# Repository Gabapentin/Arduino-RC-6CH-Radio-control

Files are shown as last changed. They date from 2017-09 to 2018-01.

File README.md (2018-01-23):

# Arduino-RC-6CH-Radio-control

----------------------------------------------------------------------------------------------------------

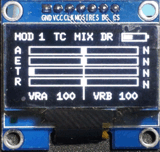
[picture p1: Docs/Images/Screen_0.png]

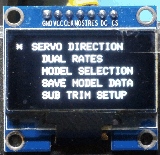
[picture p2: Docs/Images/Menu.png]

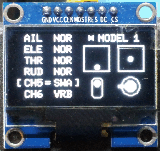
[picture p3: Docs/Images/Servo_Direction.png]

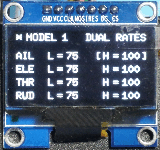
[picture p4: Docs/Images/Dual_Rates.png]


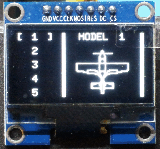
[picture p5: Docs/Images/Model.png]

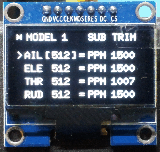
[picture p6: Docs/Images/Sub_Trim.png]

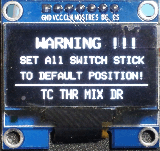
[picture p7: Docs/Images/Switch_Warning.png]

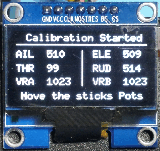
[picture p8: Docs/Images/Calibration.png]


| FS-CT6B | | HK-T6A |
| --- | :---: | --- |
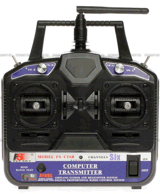
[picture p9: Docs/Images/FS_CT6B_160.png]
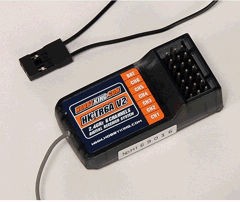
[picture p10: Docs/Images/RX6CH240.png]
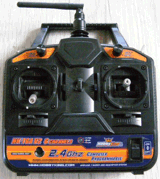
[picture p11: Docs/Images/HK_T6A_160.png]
|  |  |  | 

Arduino project to upgrade cheap Hobbyking HK-T6A or Flysky FS-CT6B transmitters or any other old RC TX    

This code is based on ardutx v1.3 sketch (2014) from Patricio Reinoso www.patolin.com    

**You can see discussion on RCGroups Forum site**    
https://www.rcgroups.com/forums/showthread.php?1817699-Hobbyking-6ch-tx-arduino-computer-update

**If you want discuss this project I have already open thread on RCGroups**    
https://www.rcgroups.com/forums/showthread.php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 

----------------------------------------------------------------------------------------------------------

The code has been modified to work with SH1106 SPI 1.3" or SSD1306 SPI 0.96" OLED LCD through U8g2 library

Have been used all possible pins of ATmega328P (Arduino Nano, Pro Mini)

Every text strings has been stored in flash memory to mantain a lot of free RAM memory

----------------------------------------------------------------------------------------------------------

Added features to original Patolin code:

- 3 digital buttons input for menu (Enter/Select) (Down/Next) (Up/Previous) [previously analogs]

- Switches checking status with sound alert at power ON and display which is not in default position 

- Throttle warning with display status of switches and sound alert

- Hidden data default restoring by pressing and hold Down/Next button on power on

- Hidden calibration procedure by pressing and hold Menu/Select button on power on

- Low battery control in real time whith buzzer sound(buzzer with stand alone sound generator)

- N°2 supplementary switch, they can be configured instead of VRA or VRB pots (SWA, SWB)(Servo Direction Menu)

- Basic two channel mixer with switch activation V-Mix (Ch1/ch2)

- Basic four channels Sub Trim setting (ch1, ch2, ch3, ch4)

*************************************************************************************************************

Recommended Arduino **[Arduino IDE 1.8.2 or above](https://www.arduino.cc/en/main/software)**    
(Seems to be optimized and stable compiler. Less Flash and RAM used)

Arduino AVR Boards 1.6.18

#include <U8g2lib.h>               Using U8G2 library **[UG2 Github link](https://github.com/olikraus/U8g2_Arduino)**

#include <SPI.h>                   Arduino standard library

#include <EEPROM.h>                Arduino standard library    

### **[See Wiki pages](https://github.com/Gabapentin/Arduino-RC-6CH-Radio-control/wiki)**

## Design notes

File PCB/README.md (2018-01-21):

This directory will contain Eagle files for PCB production
you can make your own PCB    
For one layer PCB seems to be comfortable to use Arduino NANO version
* #### **WITH TRANSMITTER POWERED DIRECTLY FROM BATTERY** 
#### **DO NOT USE this PCB for Hobbyking HK-T6A or Flysky FS-CT6B original Transmitter module**
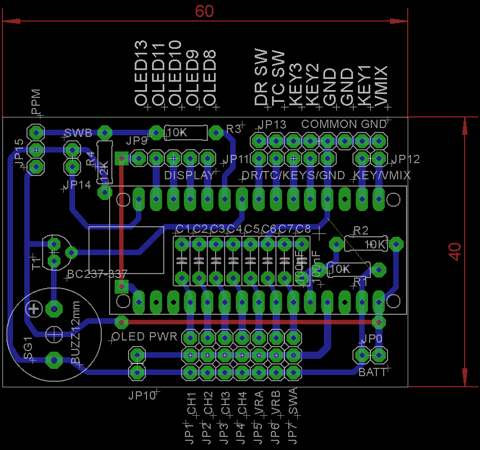
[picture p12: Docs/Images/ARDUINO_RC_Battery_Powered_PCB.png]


***

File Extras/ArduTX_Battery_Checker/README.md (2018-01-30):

## **Sketch file for calibrate battery and testing low battery alarm with OLED display**

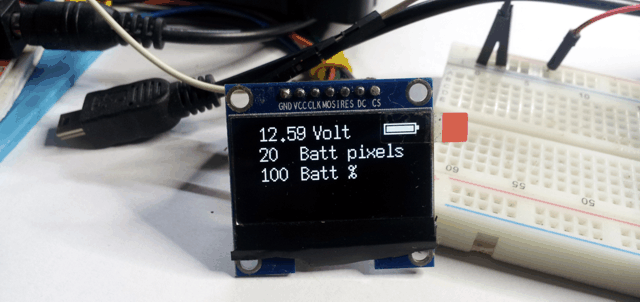
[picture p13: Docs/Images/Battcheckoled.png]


This sketch want provide help for testing and calibrate battery value from Arduino pin    
with low battery alarm functionality through OLED display (without connecting buzzer)    

**NOTES and safety WARNING:**

   - Use linear voltage variable power supply to simulate voltage battery, when it possible.
   
   - If you want a correct visualization of values after uploading sketch in Arduino    
     is necessary remove USB programming cable from PC because it makes readings unstable.  
   - **[Must be used R1-10K/R2-10K voltage divider for 2S(8.4V) lion/LiPo battery](https://github.com/Gabapentin/Arduino-RC-6CH-Radio-control/wiki/4.6-(Battery-Monitor-Wiring))**    
   - **[Must be used R1-20K/R2-10K voltage divider for 3S(12.6V) lion/LiPo battery](https://github.com/Gabapentin/Arduino-RC-6CH-Radio-control/wiki/4.6-(Battery-Monitor-Wiring))**
   - **For 2S voltage divider do not over 10V, For 3S voltage divider do not over 15V.
     Otherwise Arduino pin will be fried.**
     
   - **WARNING: If you want reset ALARM OLED display indication!    
     is necessary to put battery voltage to the maximum and restart Arduino with reset button**  

  ## For testing you can modify these parameters:
   
   **Number of reading to calculate average    
   lower value means fast reaction, high value slow reaction (8 value is maximum)**
   
```javascript
   const int numReadings = 8;
   ```
   ```javascript
   #define minBat 70     // Minimum battery voltage for alarm (70 = 7.0V)for 2S LiOn/LiPo battery
   #define maxBat 82     // Maximum battery voltage (10V) (82 = 8.2V)for 2S LiOn/LiPo battery
  
   ++++++++++++++++++++++++++++++++++++++++++++++++++++++++++++++++++++++++++++++++++++++++++++++
   #define minBat 100    // Minimum battery voltage for alarm (100 = 10V)for 3S LiOn/LiPo battery
   #define maxBat 125    // Maximum battery voltage (125 = 12.5V)for 3S LiOn/LiPo battery
   ++++++++++++++++++++++++++++++++++++++++++++++++++++++++++++++++++++++++++++++++++++++++++++++    
   ```

   **If you need more precision, measure voltage divider resistors value with digital multimeter    
   put them in to R1/R2 variables and trim these values**
   ```javascript
   float R1 = 10430;
   float R2 = 10055;
   ```
## **After ending test you need to put result values in config.h file**    

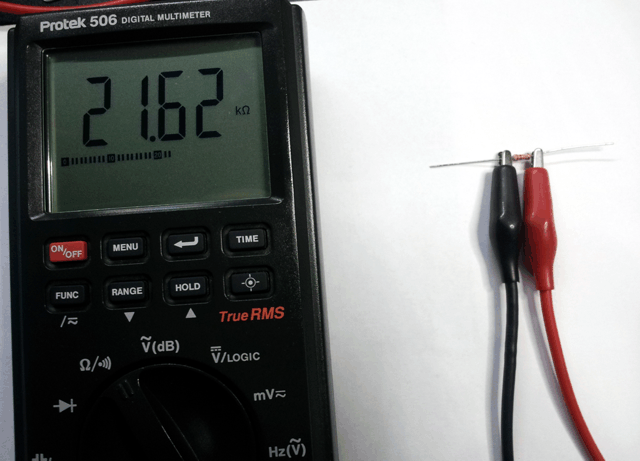
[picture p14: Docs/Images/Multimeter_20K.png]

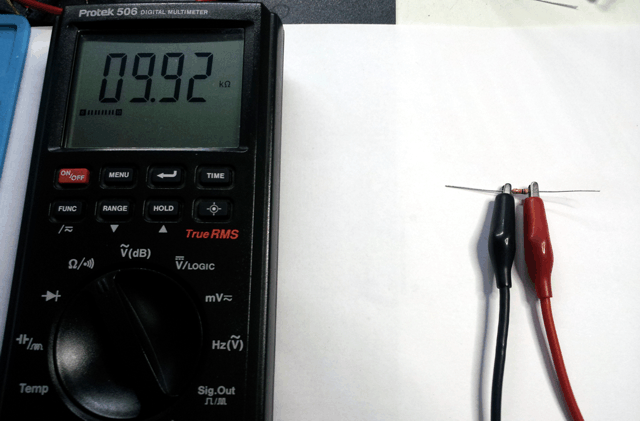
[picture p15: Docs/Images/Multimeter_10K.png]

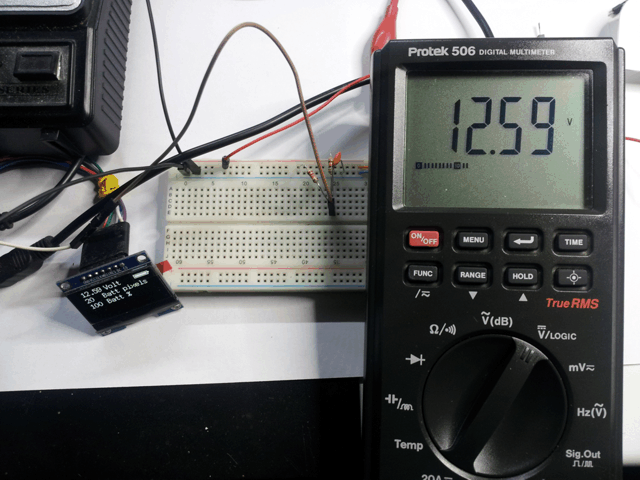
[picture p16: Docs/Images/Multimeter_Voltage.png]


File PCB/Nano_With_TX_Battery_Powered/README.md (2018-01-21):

### **Please remember at this time It's only prototype. Will be modified!** ###    
#### This directory contains all files for Arduino Nano one layer PCB shield (60x40mm dimension)   
#### This shield will provide directly battery power to TX module like **[Multiprotocol](https://github.com/pascallanger/DIY-Multiprotocol-TX-Module)** or FRSKY/FLYSKY external module     

### **DO NOT USE this PCB for Hobbyking HK-T6A or Flysky FS-CT6B original Transmitter module**
#### NOTES:
* #### Arduino Nano must be mounted on a female header socket to permit capacitors mounting under Nano module    
* #### Maximum battery voltage is 10V (2S Lion/LiPo 8.4V is enough for long time operation)
* #### For 3S 12.6V battery voltage is necessary to modify R1 to 20K and some parameters on sketch
* #### PPM voltage is reduced from voltage divider to 2.7Vpp    



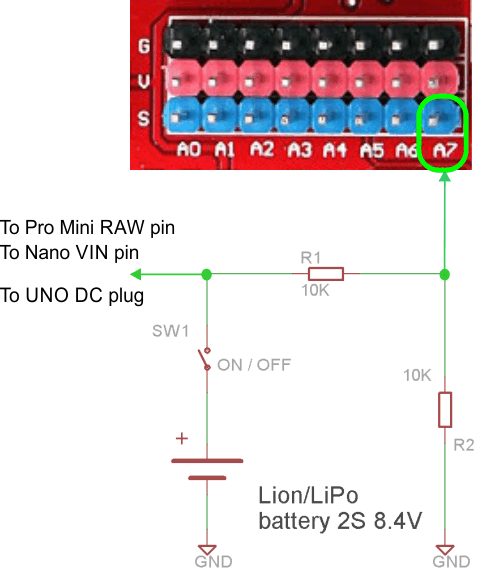
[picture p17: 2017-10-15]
Docs/Images/Battery_480.png

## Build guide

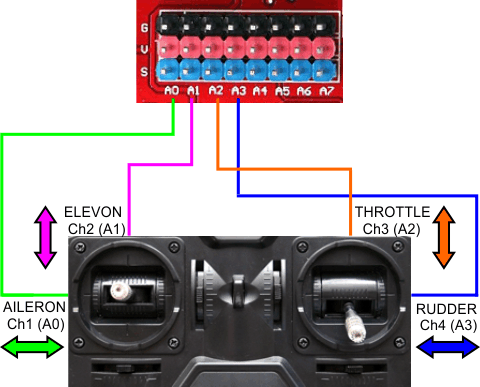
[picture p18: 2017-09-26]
Docs/Images/Gimbals_wiring_mode3_480.png

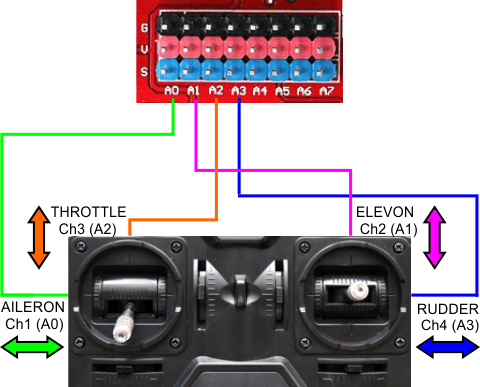
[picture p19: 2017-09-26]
Docs/Images/Gimbals_wiring_mode4_480.png

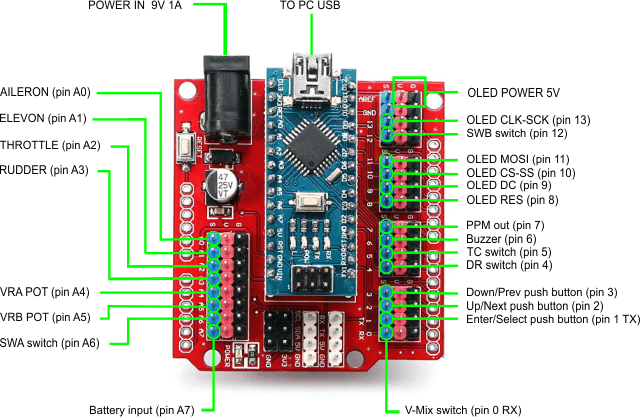
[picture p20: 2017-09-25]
Docs/Images/Arduino_Wiring.png

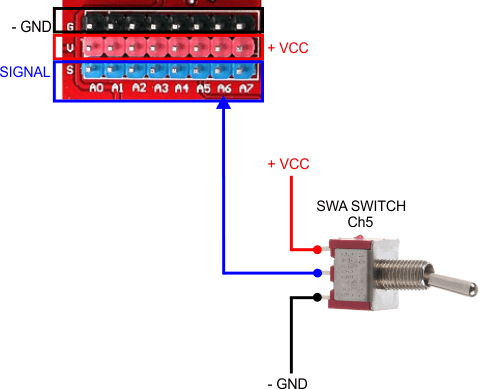
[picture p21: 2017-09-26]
Docs/Images/Switch_wiring_1_480.png

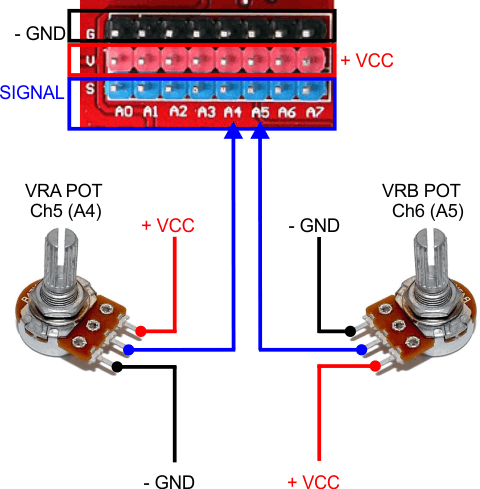
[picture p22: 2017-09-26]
Docs/Images/Pots_wiring_480.png

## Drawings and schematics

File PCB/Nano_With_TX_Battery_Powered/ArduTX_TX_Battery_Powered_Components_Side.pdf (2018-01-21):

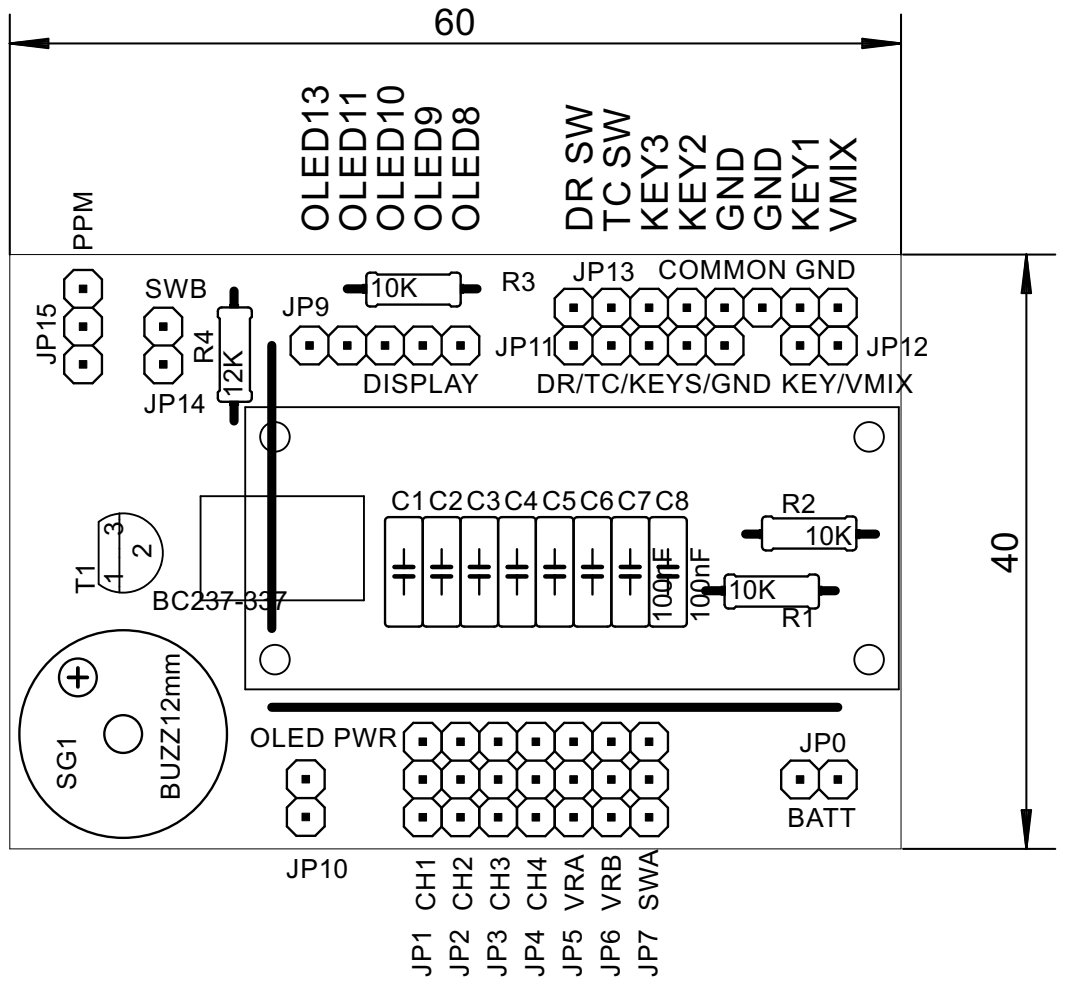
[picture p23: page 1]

DR/TC/KEYS/GND KEY/VMIX

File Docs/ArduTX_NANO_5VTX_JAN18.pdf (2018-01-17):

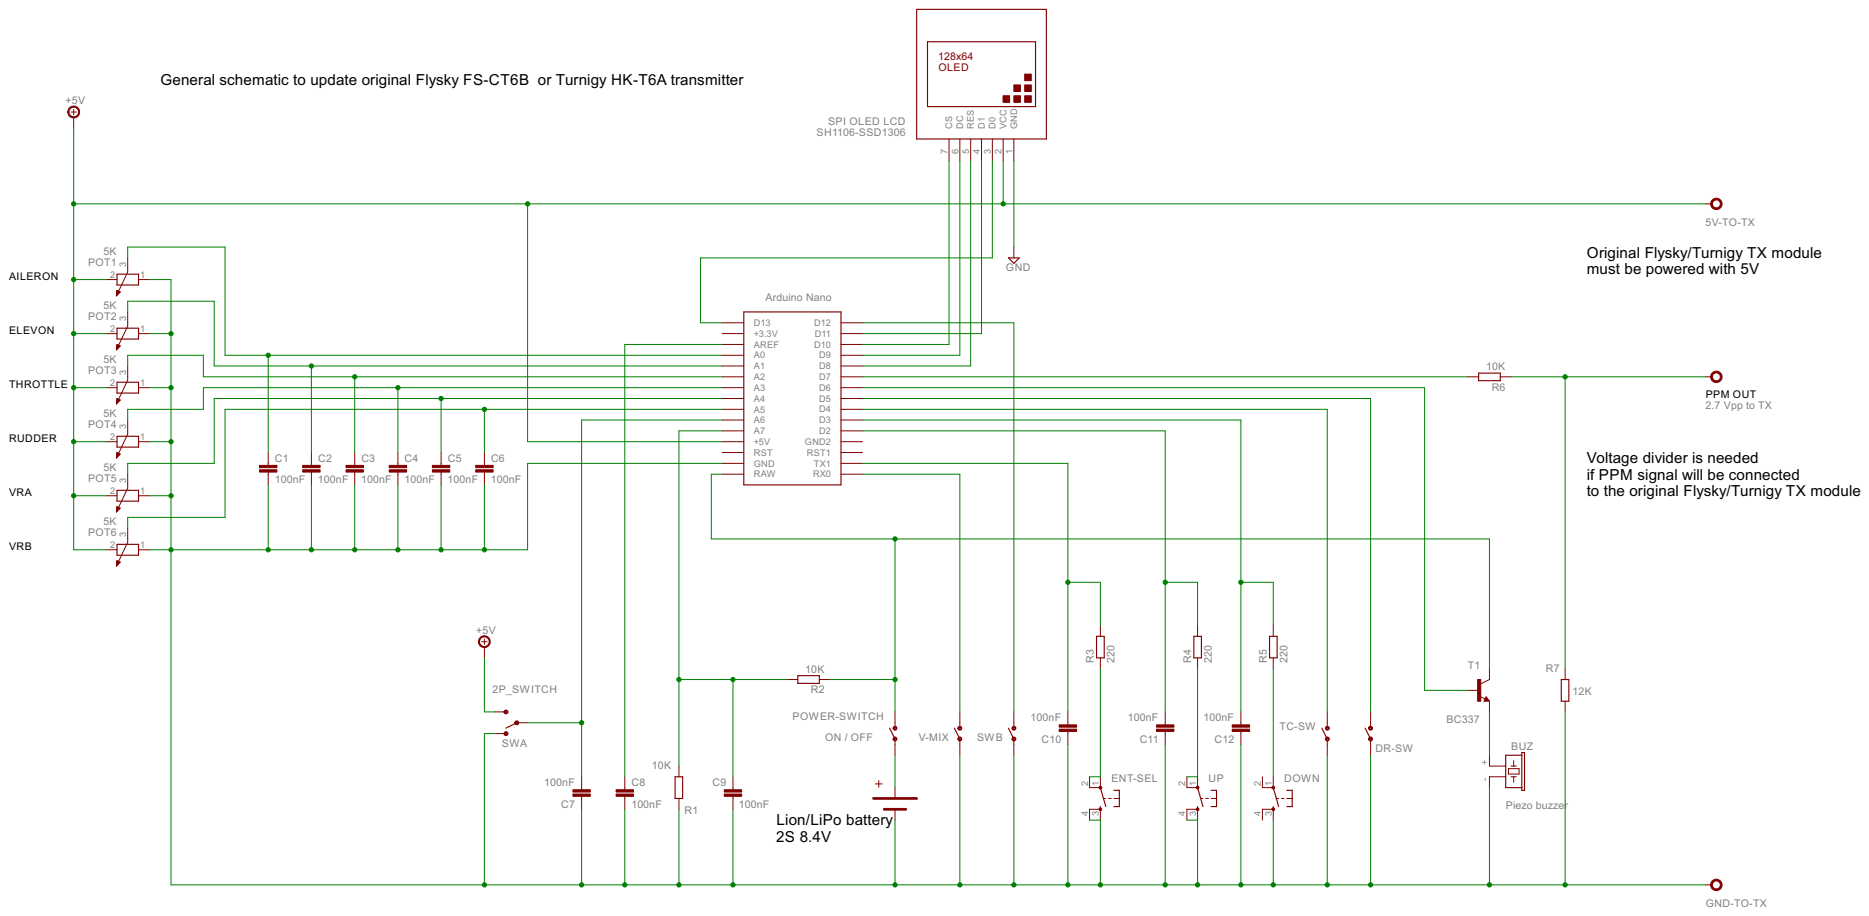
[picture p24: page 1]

General schematic to update original Flysky FS-CT6B or Turnigy HK-T6A transmitter

Original Flysky/Turnigy TX module must be powered with 5V

Voltage divider is needed
if PPM signal will be connected
to the original Flysky/Turnigy TX module

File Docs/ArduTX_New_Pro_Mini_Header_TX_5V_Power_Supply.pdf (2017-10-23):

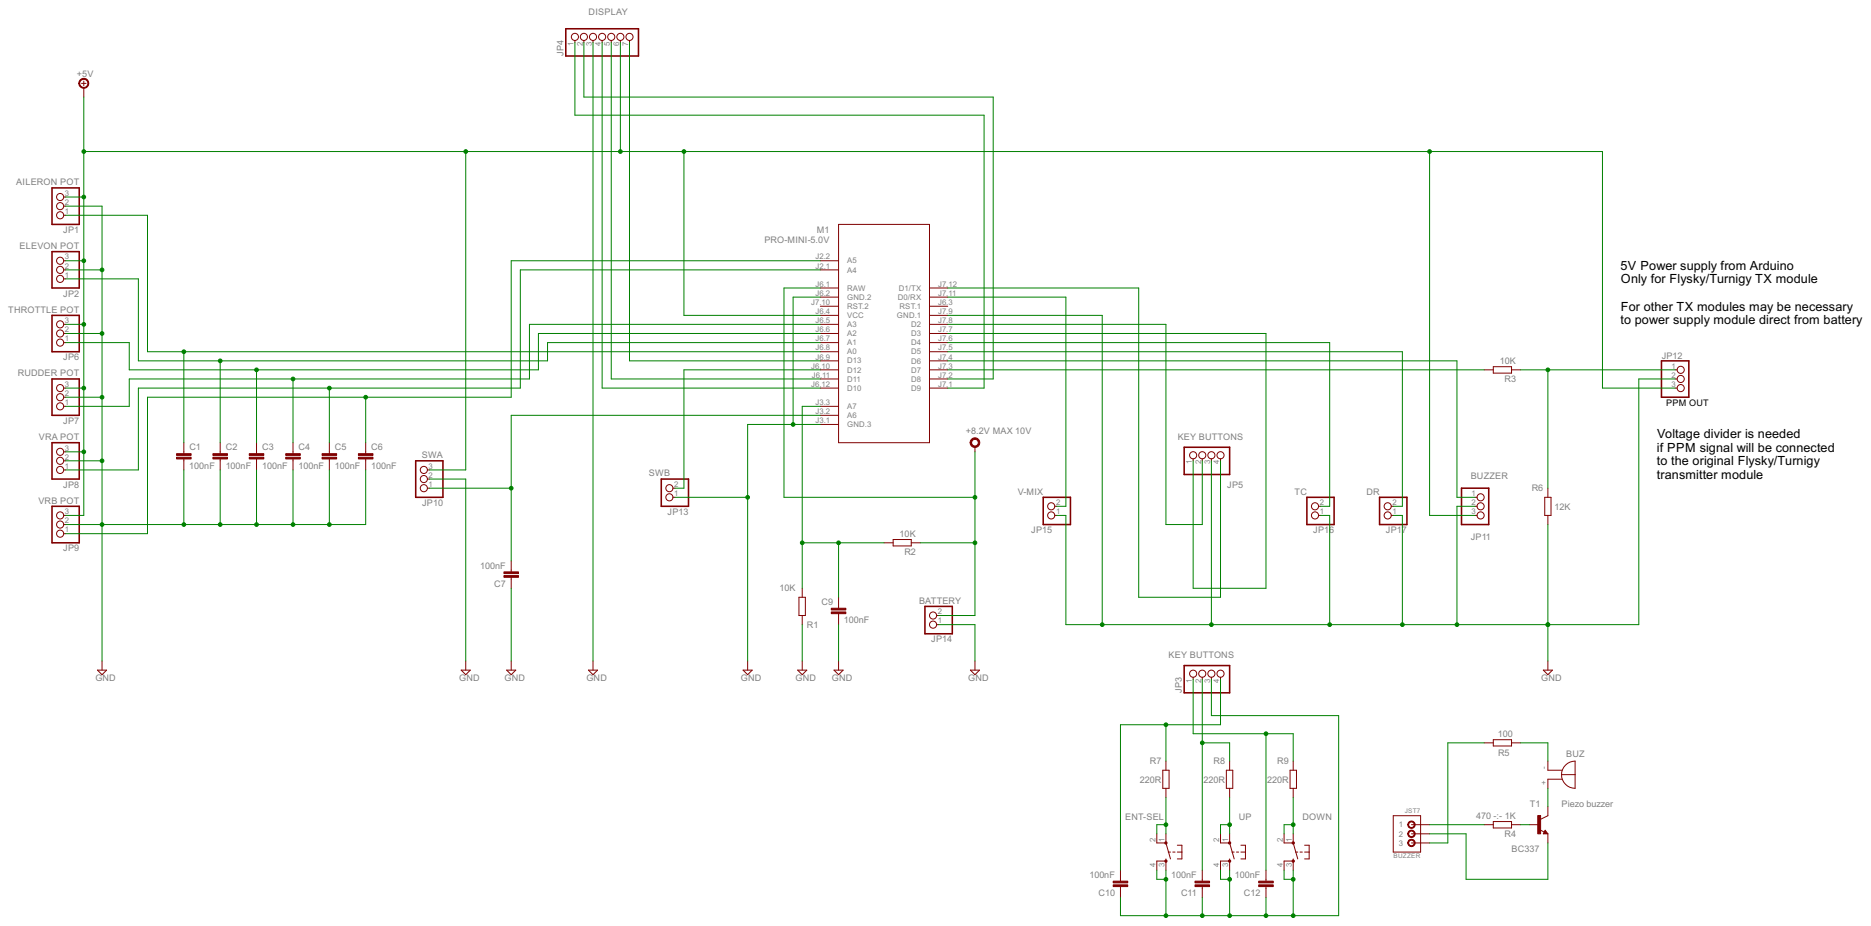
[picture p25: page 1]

AILERON POT ELEVON POT

5V Power supply from Arduino Only for Flysky/Turnigy TX module For other TX modules may be necessary

to power supply module direct from battery

if PPM signal will be connected
to the original Flysky/Turnigy
transmitter module

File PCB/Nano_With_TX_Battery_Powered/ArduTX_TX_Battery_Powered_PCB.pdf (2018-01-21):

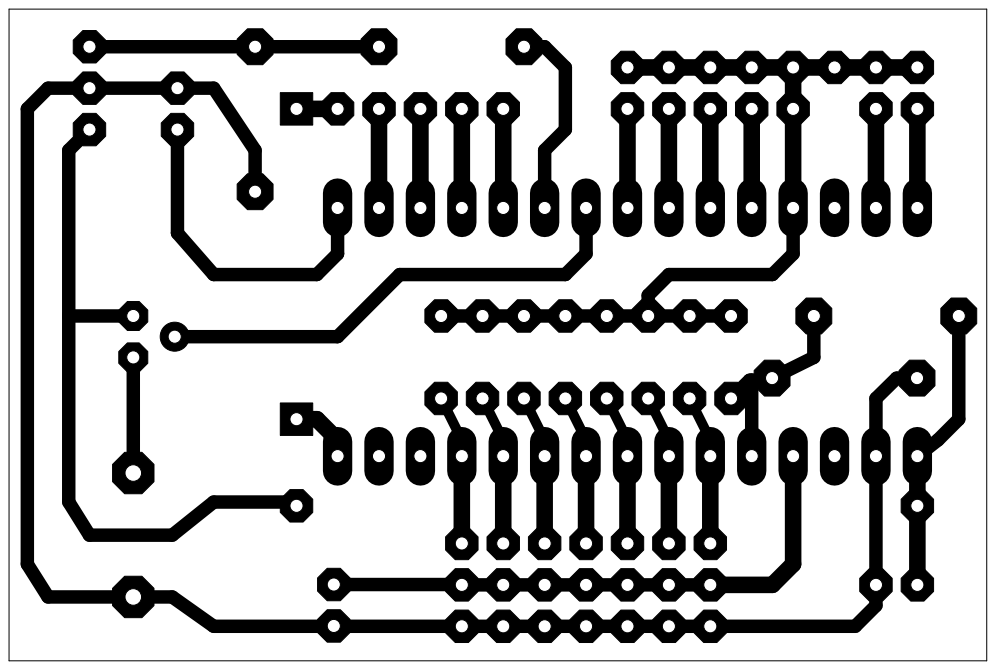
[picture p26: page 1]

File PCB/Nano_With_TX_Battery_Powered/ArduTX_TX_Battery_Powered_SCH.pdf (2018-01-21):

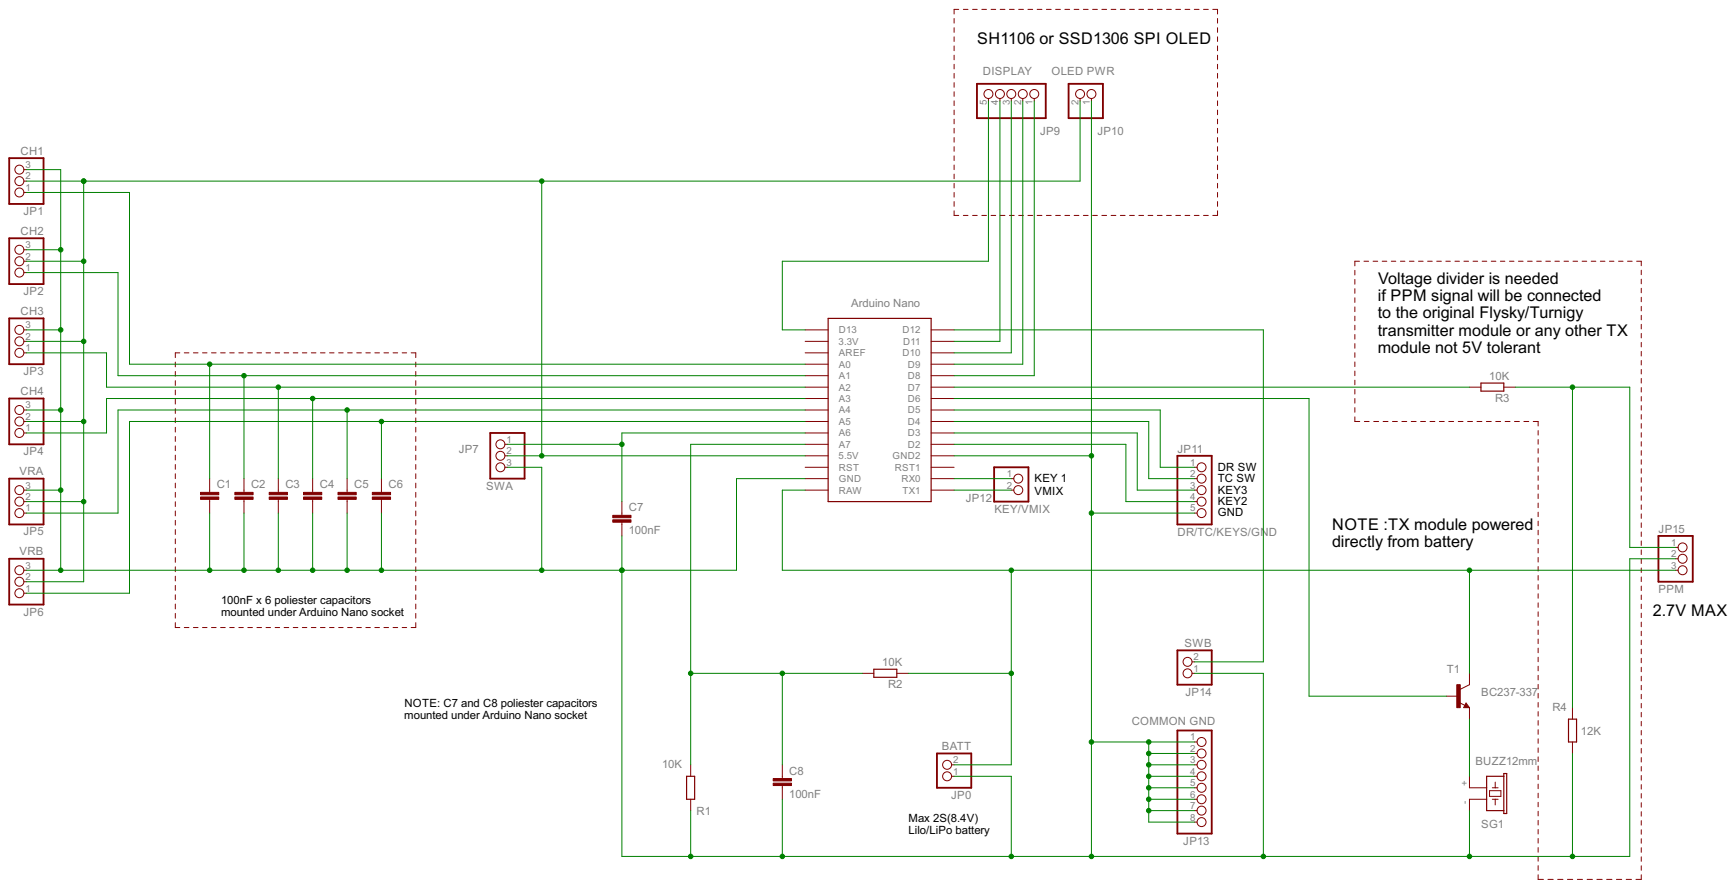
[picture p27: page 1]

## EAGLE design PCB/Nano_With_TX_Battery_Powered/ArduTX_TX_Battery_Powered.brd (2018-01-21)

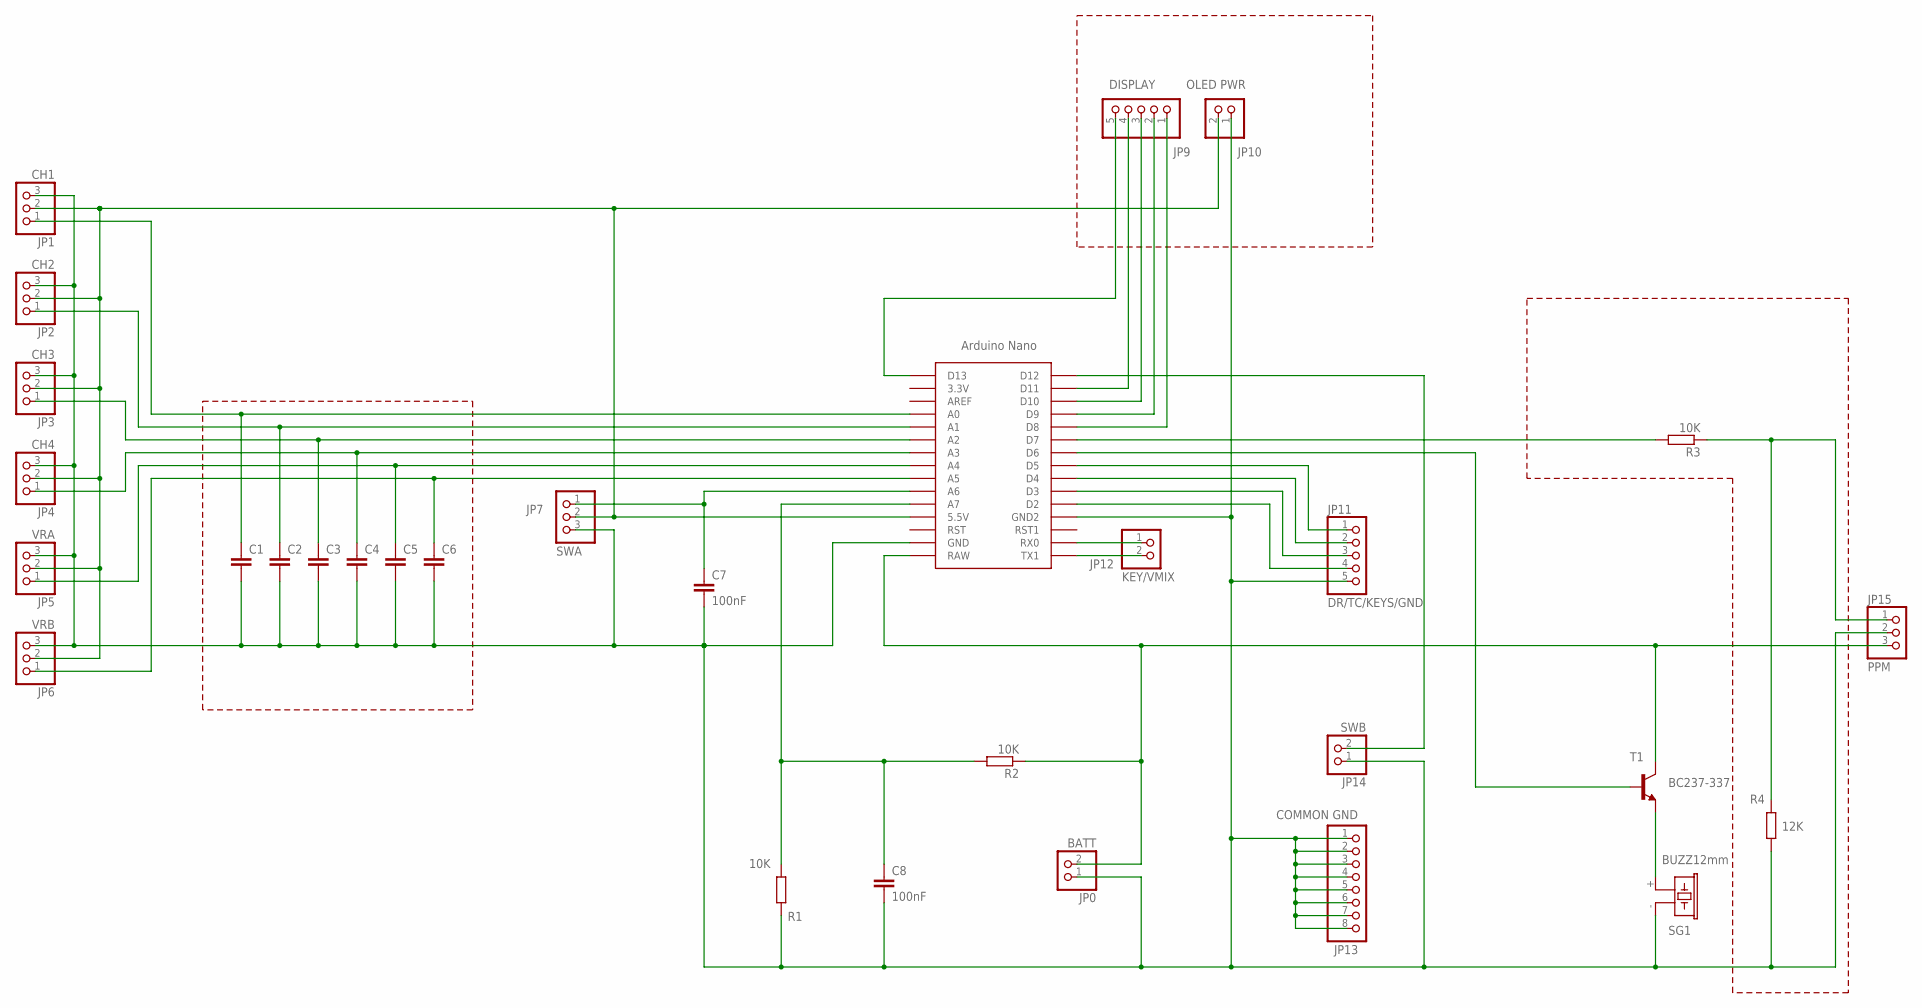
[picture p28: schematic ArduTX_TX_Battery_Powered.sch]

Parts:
ARDUINO-NANO: NANO
C1, C2, C3, C4, C5, C6: C-EU050-025X075; C050-025X075
C7, C8: 100nF; C050-025X075
JP0: BATT; 1X02
JP1: CH1; 1X03
JP2: CH2; 1X03
JP3: CH3; 1X03
JP4: CH4; 1X03
JP5: VRA; 1X03
JP6: VRB; 1X03
JP7: SWA; 1X03
JP9: DISPLAY; 1X05
JP10: OLED PWR; 1X02
JP11: DR/TC/KEYS/GND; 1X05
JP12: KEY/VMIX; 1X02
JP13: COMMON GND; 1X08
JP14: SWB; 1X02
JP15: PPM; 1X03
R1, R2, R3: 10K; 0207/8
R4: 12K; 0207/8
SG1: BUZZ12mm; F/CM12P
T1: BC237-337; TO92

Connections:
unnamed: ARDUINO-NANO.TX0 (TX1), JP12.2
unnamed: ARDUINO-NANO.5V (5.5V), JP1.2, JP2.2, JP3.2, JP4.2, JP5.2, JP6.2, JP7.2, JP10.2
unnamed: ARDUINO-NANO.A0, C1.1, JP1.1
unnamed: ARDUINO-NANO.A1, C2.1, JP2.1
unnamed: ARDUINO-NANO.A2, C3.1, JP3.1
unnamed: ARDUINO-NANO.A3, C4.1, JP4.1
unnamed: ARDUINO-NANO.A4, C5.1, JP5.1
unnamed: ARDUINO-NANO.A5, C6.1, JP6.1
unnamed: ARDUINO-NANO.D6, T1.2 (B)
unnamed: SG1.+ (1), T1.1 (E)
unnamed: ARDUINO-NANO.D7, R3.2
unnamed: ARDUINO-NANO.RX1 (RX0), JP12.1
unnamed: ARDUINO-NANO.D4, JP11.2
unnamed: ARDUINO-NANO.D5, JP11.1
unnamed: ARDUINO-NANO.A6, C7.1, JP7.1
unnamed: ARDUINO-NANO.D3, JP11.3
unnamed: ARDUINO-NANO.D2, JP11.4
unnamed: ARDUINO-NANO.A7, C8.1, R1.1, R2.2
unnamed: ARDUINO-NANO.D12, JP14.2
unnamed: ARDUINO-NANO.GND, ARDUINO-NANO.GND1 (GND2), C1.2, C2.2, C3.2, C4.2, C5.2, C6.2, C7.2, C8.2, JP0.1, JP1.3, JP2.3, JP3.3, JP4.3, JP5.3, JP6.3, JP7.3, JP10.1, JP11.5, JP13.1, JP13.2, JP13.3, JP13.4, JP13.5, JP13.6, JP13.7, JP13.8, JP14.1, JP15.2, R1.2, R4.1, SG1.- (2)
unnamed: ARDUINO-NANO.D10, JP9.3
unnamed: ARDUINO-NANO.D9, JP9.2
unnamed: ARDUINO-NANO.D8, JP9.1
unnamed: ARDUINO-NANO.D11, JP9.4
unnamed: ARDUINO-NANO.D13, JP9.5
unnamed: JP15.1, R3.1, R4.2
NET: ARDUINO-NANO.RAW, JP0.2, JP15.3, R2.1, T1.3 (C)

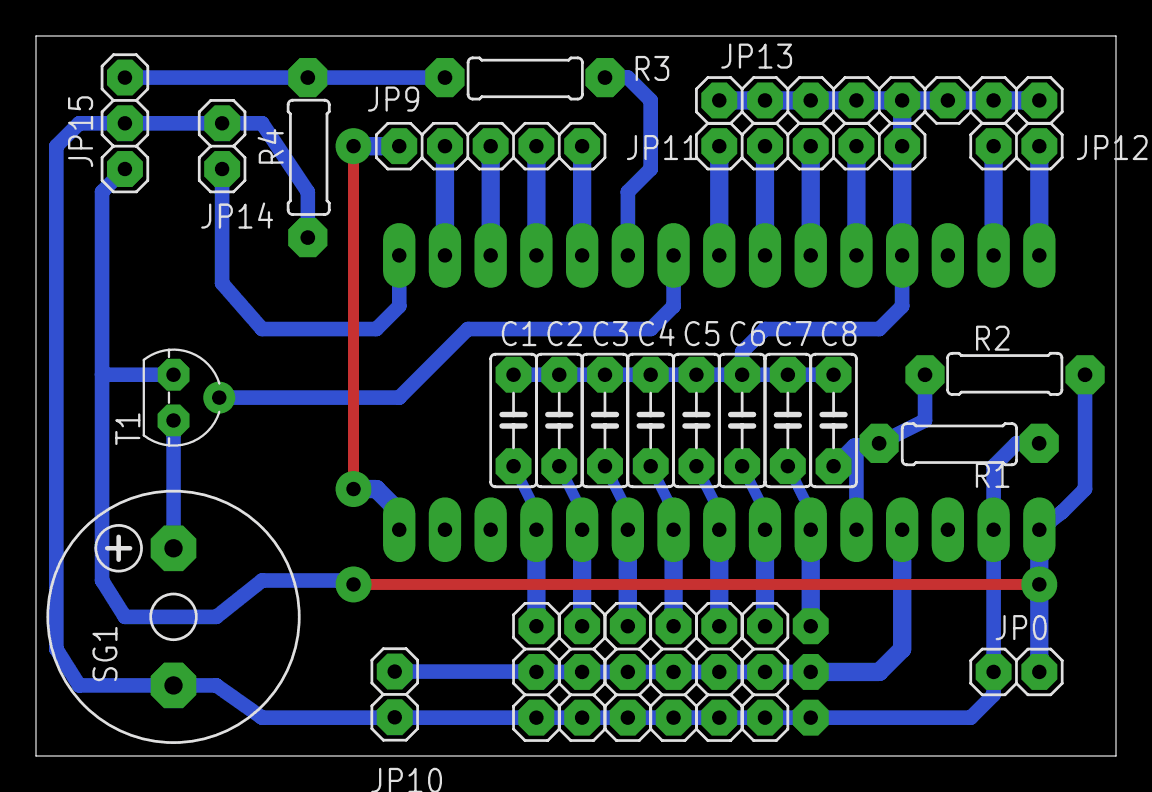
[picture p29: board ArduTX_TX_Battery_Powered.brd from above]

Board: 2 copper layers, 60.0 x 40.0 mm, 30 parts (1 on the bottom side), 27 nets.

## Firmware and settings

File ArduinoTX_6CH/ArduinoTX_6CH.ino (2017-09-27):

// This code is based on ardutx v1.3 sketch
// (c) 2014 Patricio Reinoso
// www.patolin.com

/* This project is free software: you can redistribute it and/or modify
  it under the terms of the GNU General Public License as published by
  the Free Software Foundation, either version 3 of the License, or
  (at your option) any later version.
  this code is distributed in the hope that it will be useful,
  but WITHOUT ANY WARRANTY; without even the implied warranty of
  MERCHANTABILITY or FITNESS FOR A PARTICULAR PURPOSE. See the
  GNU General Public License for more details.
  You should have received a copy of the GNU General Public License
  along with this code. If not, see <http://www.gnu.org/licenses/>.*/

// *************************************************************************************************************
// A great Patolin idea to upgrade cheap Hobbyking HK-T6A or Flysky FS-CT6B transmitters or any other old RC TX
// These transmitters offer a configuration through a serial port with an external PC software program
// and no space to store more than one model.
// *************************************************************************************************************
// This sketch has been modified to work with SH1106 SPI 1.3" or SSD1306 SPI 0.96" OLED display through U8g2 library
// Has been used all possible pins of ATmega328 (Arduino UNO, Nano, Pro Mini)
// Every text strings has been stored in flash memory to mantain a lot of free RAM memory
// Sketch terms, text, items has been translated in English to ease users/developers
// *************************************************************************************************************
// Added features to original Patolin code:
// - Support for SH1106 SPI 1.3" or SSD1306 SPI 0.96"(128x64)(U8g2 library)
// - Switches checking status with sound alert at power ON and display which is not in default position
// - Throttle warning with display status and sound alert
// - Hidden data default restoring by pressing and hold Down/Next button on power on
// - Hidden calibration procedure by pressing and hold Menu/Select button on power on
// - Low battery control in real time whith buzzer sound(buzzer with stand alone sound generator)
// - N°2 supplementary switch, they can be configured instead of VRA or VRB pots(SWA, SWB)(Servo Direction Menu)
// - Basic two channel mixer with switch activation V-Mix (Ch1/ch2)
// - Basic four channels Sub Trim setting (ch1, ch2, ch3, ch4)
// *************************************************************************************************************
// Recommended Arduino IDE 1.8.2 // Seems to be optimized and stable compiler. Less Flash and RAM used
// Arduino AVR Boards 1.6.18
// *************************************************************************************************************
/*
  +++++++++++++++++
  Input Pots
  6 channels
  +++++++++++++++++
  Aileron  CH1 = A0
  Elevon   CH2 = A1
  Throttle CH3 = A2
  Rudder   CH4 = A3
  Pot VRA  CH5 = A4
  Pot VRB  CH6 = A5

  //---------------------------------------------------------------------------------------------
  // 2 position switch (pin A6 in the center, VCC and GND at both ends)
  // NOTE: switch is activated when pin A6 is closed to GND (normaly closed to VCC)
  //---------------------------------------------------------------------------------------------
  swA = A6

  //---------------------------------------------------------------------------------------------
  // Must be used R1-10K/R2-10K voltage divider for 2S lion/LiPo battery
  // (R1-20K/R2-10K voltage divider for 3S lion/LiPo battery)
  //---------------------------------------------------------------------------------------------
  batPin = A7

  (Battery voltage divider)

  Vbatt MAX 10V ----+
                   |
                   R1 10K
                   |
                   |+-----> (PIN A7)
                   |
                   R2 10K
                   |
                   =
                   .  (GND)

  //---------------------------------------------------------------------------------------------
  // V-Mix switch
  // WARNING !!! If closed to GND will deny to upload sketch
  //---------------------------------------------------------------------------------------------
  swMix = pin 0[RXD]

  //---------------------------------------------------------------------------------------------
  // Mount 0,1uF/100nF(104)ceramic capacitor from pin to GND
  // WARNING !!! the capacitor on pin 1[TXD](buttonSelect) will deny to upload sketch
  //---------------------------------------------------------------------------------------------
  Enter Button pin 1(TXD)
  UP Button    pin 2
  Down Button  pin 3

  //---------------------------------------------------------------------------------------------
  // 2 position switch (is activated when pin is closed to GND)
  //---------------------------------------------------------------------------------------------
  swDR         pin 4
  swTC         pin 5
  swB          Pin 12

  //---------------------------------------------------------------------------------------------
  buzzer       pin 6   // Buzzer with sound generator (need transistor driving)

  //---------------------------------------------------------------------------------------------
  // Must be used voltage divider on pin 7 to limit at 3Vpp ppm signal
  // because T6A/CT6B(A7105)TX module is not 5V tollerant
  //---------------------------------------------------------------------------------------------
  sigPin       pin 7

  (PPM Signal voltage divider)

  sigPin 7 ----------+
                   |
                   R1 10K
                   |
                   |+-----> 2.7Vpp(to TX PPM PIN)
                   |
                   R2 12K(Max 15K)
                   |
                   =
                   .  (GND)
*/
//++++++++++++++++++++++++++++++++++++++++++++++++++++++++++++++++++++++++++++++++++++++++++++++++++++++++
#include <SPI.h>                   // Arduino standard library
#include <EEPROM.h>                // Arduino standard library
#include <U8g2lib.h>               // Using U8G2 library "https://github.com/olikraus/u8g2"
#include "Config.h"                // Load static and variable configuration settings
//++++++++++++++++++++++++++++++++++++++++++++++++++++++++++++++++++++++++++++++++++++++++++++++++++++++++

void setup() {

  //Serial.begin(9600);

  // LCD config with U8G2 library display init (mandatory)
  u8g2.begin();

  // +++++++++++++++++++++++++++++++++++++++++++++++++++++++++++++++++++++++++++++++++++++++++++++++
  // Input ADC sampling rate for reading analog input pots (1000 KHz is maximum for stable reading)
  // +++++++++++++++++++++++++++++++++++++++++++++++++++++++++++++++++++++++++++++++++++++++++++++++

  ADCSRA &= ~(1 << ADPS2) | (1 << ADPS1) | (1 << ADPS0);   // Remove bit settings from Arduino library
  ADCSRA |= (1 << ADPS2);                                  // Set ADC prescaler to 16 (1000 KHz)

  ADMUX |= (1 << REFS0);
  ADMUX &= ~(1 << REFS1);                                  // Avcc(+5v) as voltage reference

  ADCSRB &= ~((1 << ADTS2) | (1 << ADTS1) | (1 << ADTS0)); // ADC in free-running mode

  ADCSRA |= (1 << ADEN);                                   // Turn on ADC
  ADCSRA |= (1 << ADSC);                                   // Do an initial conversion this one is the slowest to ensure that everything is up and running

  DIDR0 = 0x3F;                                            // Digital circuit on analog ports disabled
  DIDR1 = 0x03;                                            // Disable digital input on AIN0/1

  //+++++++++++++++++++++++++++++++++++++++++++++++++++++++++++++++++++++++++++++++++++++
  // Debouncing mechanical buttons
  // NOTE: For input pin buttons is necessary to mount on every pin
  // 0,1uF/100nF(104)ceramic capacitors from pin to GND
  // WARNING !!! the capacitor on pin 1(buttonSelect) will deny to upload sketch
  //+++++++++++++++++++++++++++++++++++++++++++++++++++++++++++++++++++++++++++++++++++++
  pinMode(buttonSelect, INPUT);          // Pull up is not necessary (pin on LED TXD)
  pinMode(buttonUp, INPUT_PULLUP);
  pinMode(buttonDown, INPUT_PULLUP);
  //+++++++++++++++++++++++++++++++++++++++++++++++++++++++++++++++++++++++++++++++++++++
  pinMode(swTC, INPUT_PULLUP);
  pinMode(swDR, INPUT_PULLUP);
  pinMode(swB,  INPUT_PULLUP);
  pinMode(swMix, INPUT);                 // Pull up is not necessary (pin on LED RXD)
  pinMode(buzzer, OUTPUT);
  //+++++++++++++++++++++++++++++++++++++++++++++++++++++++++++++++++++++++++++++++++++++

  res_calc = (R1 + R2) / R2;             // Voltage divider calculation

  //+++++++++++++++++++++++++++++++++++++++++++++++++++++++++++++++++++++++++++++++++++++
  // Initialize value for average ADC readings
  //+++++++++++++++++++++++++++++++++++++++++++++++++++++++++++++++++++++++++++++++++++++

  for (int thisReading = 0; thisReading < numReadings; thisReading++)

    readings[thisReading] = 0; // initialize all the readings to 0

  //+++++++++++++++++++++++++++++++++++++++++++++++++++++++++++++++++++++++++++++++++++++
  // Default state values for ppm
  //+++++++++++++++++++++++++++++++++++++++++++++++++++++++++++++++++++++++++++++++++++++
  ppm[0] = servoCenter;     // channel 1 (A)
  ppm[1] = servoCenter;     // channel 2 (E)
  ppm[2] = ppmMin;          // channel 3 (T)
  ppm[3] = servoCenter;     // channel 4 (R)
  ppm[4] = ppmMin;          // channel 5 (VRA,SWA)
  ppm[5] = ppmMin;          // channel 6 (VRB,SW2)

  //+++++++++++++++++++++++++++++++++++++++++++++++++++++++++++++++++++++++++++++++++++++
  // Default state config parameters
  //+++++++++++++++++++++++++++++++++++++++++++++++++++++++++++++++++++++++++++++++++++++

  // Servo Direction bit mask: 0 Normal, 1 Reverse
  servoReverse = 0b00000000;

  // Dual Rates and Sub Trim default values (only for first four channels)
  for (int i = 0; i < CHANNELS - 2; i++) {

    dual_rate_low[i] = 75;
    dual_rate_hi[i] = 100;
    subTrim[i] = 512;
  }

  //+++++++++++++++++++++++++++++++++++++++++++++++++++++++++++++++++++++++++++++++++++++
  // Config output signal pin
  //+++++++++++++++++++++++++++++++++++++++++++++++++++++++++++++++++++++++++++++++++++++
  DDRD |= _BV(sigPin);  // Set pin 7 as an output
  PORTD ^= _BV(sigPin); // Set pin 7 toggle state

  //+++++++++++++++++++++++++++++++++++++++++++++++++++++++++++++++++++++++++++++++++++++
  // ppm timer config
  //+++++++++++++++++++++++++++++++++++++++++++++++++++++++++++++++++++++++++++++++++++++
  configTimer1();

  //+++++++++++++++++++++++++++++++++++++++++++++++++++++++++++++++++++++++++++++++++++++
  // Hold button "Down" on power ON to initialize default memory data
  // Will only write data settings to default (not erase calibration data)
  //+++++++++++++++++++++++++++++++++++++++++++++++++++++++++++++++++++++++++++++++++++++

  // Delay before reading button (about charge capacitor pulse on pin)
  delay(100);

  if ((PIND & (1 << 3)) == 0) {

    // Recall "Reset to default" macro
    resetEeprom();

    u8g2.firstPage();
    do {

      // Set font type
      u8g2.setFont(u8g2_font_fub14_tr);

      // Set memory buffer for text strings
      char msg_buffer[21];

      // Print "ERASE DATA" text string
      strcpy_P(msg_buffer, (char*)pgm_read_word(&(messages[5])));
      u8g2.setCursor(0, 40);
      u8g2.print(msg_buffer);

    } while (u8g2.nextPage());

    delay(2000); // Screen message for 2sec)
  }

  //+++++++++++++++++++++++++++++++++++++++++++++++++++++++++++++++++++++++++++++++++++++
  // Load data from Eeprom
  //+++++++++++++++++++++++++++++++++++++++++++++++++++++++++++++++++++++++++++++++++++++
  modelActual = storedDataEeprom(255);
  // ++++++++++++++++++++++++++++++++++++++++++++++++++++++++++++++++++++++++++++++++++++++


  //+++++++++++++++++++++++++++++++++++++++++++++++++++++++++++++++++++++++++++++++++++++
  // Set default font type used for all display sessions (mandatory)
  //+++++++++++++++++++++++++++++++++++++++++++++++++++++++++++++++++++++++++++++++++++++
  u8g2.setFont(u8g2_font_6x10_tr);
}

// End of Setup +++++++++++++++++++++++++++++++++++++++++++++++++++++++++++++++++++++++++

void loop() {

  // Start Calibration screen if button Enter/Select is pressed on power on ***********************

  if (readKeys() == 2 && statusCalib == 1) {

    Calibration();    // Recall calibration procedure
  }

  // Set condition 0 to continue loop if calibration procedure is not selected
  else {
    statusCalib = 0;
  }

  // Start of checking switches default status ****************************************************

  readSwitches();     // Read sw_status switches values

  // This conditions check all switches and throttle status on startup if not in default position
  while (onStartup == 1 && (
           bitRead(sw_status, 0) == 0 ||
           bitRead(sw_status, 1) == 0 ||
           bitRead(sw_status, 2) == 0 ||
           bitRead(sw_status, 3) == 0 ||
           bitRead(sw_status, 4) == 0 ||
           bitRead(sw_status, 5) == 0 ))
  {
    WarnSwitch();     // Recall switch warning screen
  }

  // Set condition = 0 to continue loop after all switches are in default mode
  onStartup = 0;

  // Starting main session *************************************************************************

  readPots();                 // Recall macro for calculating ppm output

  readSwitches();             // Read switches values

  batteryCheck();             // Checking battery status

  // Start of screen display management ************************************************************

  if (screen == 0) {          // Print and drawing main screen
    Screen_0();
  }
  else {
    if (screen == 1) {        // Print menu selection screen
      Screen_1();
    }
    if (screen == 2) {

      if (menuActual == 1) {  // Execute "Servo Direction" task
        Menu_1();
      }
      if (menuActual == 2) {  // Execute "Dual Rates" task
        Menu_2();
      }
      if (menuActual == 3) {  // Execute "Model Selection" task
        Menu_3();
      }
      if (menuActual == 4) {  // Execute "Save Model Data" task
        Menu_4();
      }
      if (menuActual == 5) {  // Execute "Sub Trim Setup" task
        Menu_5();
      }
    }
  }
  // If pressed buttonSelect/Enter
  if (readKeys() == 2) {
    if (screen < 2) {
      screen++;
      menuActual = menuSubActual;
      menuSubActual = 0;
      menuSubModel = 0;
    }
    else {
      //++++++++++++++++++++++++++++++++++++++++++++++++++++++++++++++++++++++++++++++
      // Added if Menu/Select button is pressed without menu cursor (do nothing)
      //++++++++++++++++++++++++++++++++++++++++++++++++++++++++++++++++++++++++++++++
      if (menuActual == 0) {
        screen--;
        menuActual--;
      }
      //++++++++++++++++++++++++++++++++++++++++++++++++++++++++++++++++++++++++++++++
      // Options for each menu
      //++++++++++++++++++++++++++++++++++++++++++++++++++++++++++++++++++++++++++++++
      if (menuActual == 1) {

        // Selection value for Servo Direction
        bitWrite(servoReverse, menuSubActual, !bitRead(servoReverse, menuSubActual));
      }
      if (menuActual == 2) {

        // Selection value for Dual Rates
        if (drSelection != 0xFF) {
          drSelection = 0xFF;
        }
        else {
          drSelection = menuSubActual;
        }
      }

      // Model Selection data
      if (menuActual == 3) {

        // Selection value for Model Selection
        modelActual = menuSubModel;

        // Save data in eeprom
        EEPROM.update(511, modelActual);
        storedDataEeprom(modelActual);

        delay(10);
      }

      if (menuActual == 5) {

        // Selection value for Sub Trim
        if (subTrimSelection != 512) {
          subTrimSelection = 512;
        }
        else {
          subTrimSelection = menuSubActual;
        }
      }
    }
  }

  if (readKeys() == 3) {
    switch (menuActual) {

      //++++++++++++++++++++++++++++++++++++++++++++++++++++++++++++++++++++++++++
      // Dual Rate screen step control for selecting channels/values (buttonDown)
      //++++++++++++++++++++++++++++++++++++++++++++++++++++++++++++++++++++++++++
      case 2:
      
      // Initial value for Dual Rates selection value
        if (drSelection == 0xFF) {

          // Only first four channels
          if (menuSubActual < (CHANNELS * 2) - 5) {  // Two values * four channels
            menuSubActual++;
            if (screen == 0) {
              screen++;
            }
          }
        }
        // Dual Rates step control for changing selected channel value(DOWN)
        else {
          if ((drSelection % 2) == 0) {

            // Define Min for LOW Rates value
            if (dual_rate_low[drSelection / 2] > 0) {

              // Define step value
              dual_rate_low[drSelection / 2]--;
            }
          }
          else {

            // Define Min for HIGH Rates value
            if (dual_rate_hi[drSelection / 2] > 0) {

              // Define step value
              dual_rate_hi[drSelection / 2]--;
            }
          }
        }

        break;

      //+++++++++++++++++++++++++++++++++++++++++++++++++++++++++++++++++++++++++
      // Sub Trim screen step control for selecting channels/values (buttonDown)
      //+++++++++++++++++++++++++++++++++++++++++++++++++++++++++++++++++++++++++
      case 5:
      
      // Initial value for Sub Trim selection value
        if (subTrimSelection == 512) {

          // Only first four channels
          if (menuSubActual < CHANNELS - 3) {
            menuSubActual++;
            
            if (screen == 0) {
              screen++;
            }
          }
        }

        // Sub Trim step control for changing selected channel value DOWN
        else {
          if ((subTrimSelection % 1)  == 0) {

            // Define Min Sub trim value
            if (subTrim[subTrimSelection / 1] > 312 - deadBand ) {

              // Define step value
              subTrim[subTrimSelection / 1]--;
            }
          }
        }
        break;
      // +++++++++++++++++++++++++++++++++++++++++++++++++++++++++++++++++++++++++++++++

      default:
        //++++++++++++++++++++++++++++++++++++++++++++++++++++++++++++++++++++++++++++++
        // Added for Model Menu management
        //++++++++++++++++++++++++++++++++++++++++++++++++++++++++++++++++++++++++++++++
        if (menuSubModel < 4) {   // 0 to 4 items
          menuSubModel++;
          if (screen == 0) {
            screen++;
          }
        }
        //++++++++++++++++++++++++++++++++++++++++++++++++++++++++++++++++++++++++++++++

        if (menuSubActual < 5) {  // 0 to 5 items
          menuSubActual++;
          if (screen == 0) {
            screen++;
          }
        }
        break;
        //++++++++++++++++++++++++++++++++++++++++++++++++++++++++++++++++++++++++
    }
  }

  if (readKeys() == 1) {
    switch (menuActual) {

      //++++++++++++++++++++++++++++++++++++++++++++++++++++++++++++++++++++++++++
      // Dual Rate screen step control for selecting channels/values (buttonUp)
      //++++++++++++++++++++++++++++++++++++++++++++++++++++++++++++++++++++++++++
      case 2:
      
      // Initial value for Dual Rates selection value
        if (drSelection == 0xFF) {
          if (menuSubActual == 0) {
            screen--;
            menuSubActual = 1;
            menuActual = 0;
          }
          else {
            menuSubActual--;
          }
        }

        // Step control for changing selected channel value UP
        else {
          if ((drSelection % 2) == 0) {

            // Define Max for LOW Rates value
            if (dual_rate_low[drSelection / 2] < 100) {

              // Define step value
              dual_rate_low[drSelection / 2]++;
            }
          }
          else {

            // Define Max for HIGH Rates value
            if (dual_rate_hi[drSelection / 2] < 100) {

              // Define step value
              dual_rate_hi[drSelection / 2]++;
            }
          }
        }
        break;

      //+++++++++++++++++++++++++++++++++++++++++++++++++++++++++++++++++++++++
      // Sub Trim screen step control for selecting channels/values (buttonUp)
      //+++++++++++++++++++++++++++++++++++++++++++++++++++++++++++++++++++++++
      case 5:
        if (subTrimSelection == 512) {
          if (menuSubActual == 0) {
            screen--;
            menuSubActual = 1;
            menuActual = 0;
          }
          else {
            menuSubActual--;
          }
        }

        // Sub Trim step control for changing selected channel UP
        else {
          if ((subTrimSelection % 1) == 0 ) {

            // Define max value for Sub Trim
            if ((subTrim[subTrimSelection / 1]) < (712 + deadBand)) {

              // Define step value
              subTrim[subTrimSelection / 1]++;
            }
          }
        }
        break;

      //++++++++++++++++++++++++++++++++++++++++++++++++++++++++++++++++++++++++++++++++

      default:
        //++++++++++++++++++++++++++++++++++++++++++++++++++++++++++++++++++++++++++++++
        // Added for Model Menu management
        //++++++++++++++++++++++++++++++++++++++++++++++++++++++++++++++++++++++++++++++
        if (menuSubModel > 0) {
          menuSubModel--;
        }
        else {
          if (screen > 0) {
            screen--;
            menuSubModel = 1;
            menuActual = 0;
          }
        }
        //++++++++++++++++++++++++++++++++++++++++++++++++++++++++++++++++++++++++++++++

        if (menuSubActual > 0) {
          menuSubActual--;
        }
        else {
          if (screen > 0) {
            screen--;
            menuSubActual = 1;
            menuActual = 0;
          }
        }
        break;

        //++++++++++++++++++++++++++++++++++++++++++++++++++++++++++++++++++++++++++++++
    }
  }
}

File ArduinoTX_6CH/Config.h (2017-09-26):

// ++++++++++++++++++++++++++++++++++++++++++++++++++++++++++++++++++++++++++++++++++++++++++++++++++++++++
// Set library for SSD1306 SPI 0.96" OLED display TESTED OK! (128 bytes buffer)
// U8G2_SSD1306_128X64_NONAME_1_4W_HW_SPI u8g2(U8G2_R0, /* cs=*/ 10, /* dc=*/ 9, /* reset=*/ 8);

// Set library for SH1106 SPI 1.3" OLED display TESTED OK! (128 bytes buffer)
U8G2_SH1106_128X64_NONAME_1_4W_HW_SPI u8g2(U8G2_R0, /* cs=*/ 10, /* dc=*/ 9, /* reset=*/ 8);
// ++++++++++++++++++++++++++++++++++++++++++++++++++++++++++++++++++++++++++++++++++++++++++++++++++++++++
/* SPI wires cabling (OLED Pin name dependent on the manufacturer)

  OLED   Arduino
  ---------------------
  RES  > pin 8
  DC   > pin 9
  CS   > pin 10 (SS)
  MOSI > pin 11 (MOSI)
  CLK  > pin 13 (SCK)*/

// ++++++++++++++++++++++++++++++++++++++++++++++++++++++++++++++++++++++++++++++++++++++++++++++++++++++++
// config PPM settings
// ++++++++++++++++++++++++++++++++++++++++++++++++++++++++++++++++++++++++++++++++++++++++++++++++++++++++
#define servoCenter 1500             // Servo center value (us)
#define ppmLong 18500                // ppm frame (us) for 6 channels
#define ppmPulse 300                 // ppm pulse width (us)
#define onState 0                    // Polarity: 0 neg / 1 pos
#define sigPin PD7                   // ppm output pin
#define ppmMin 1000                  // Min ppm output to be mapped (us)
#define ppmMax 2000                  // Max ppm output to be mapped (us)

// ++++++++++++++++++++++++++++++++++++++++++++++++++++++++++++++++++++++++++++++++++++++++++++++++++++++++
// Config global TX param
// ++++++++++++++++++++++++++++++++++++++++++++++++++++++++++++++++++++++++++++++++++++++++++++++++++++++++
#define CHANNELS 6                   // Number of channels
#define MODELS 5                     // Total memory models 
#define potMin 0                     // Pot Min reference value
#define potMax 1023                  // Pot Max reference value
#define numBytesPerModel 32          // Maximum bytes for data storage per model

// ++++++++++++++++++++++++++++++++++++++++++++++++++++++++++++++++++++++++++++++++++++++++++++++++++++++++
// Config pin assignment
// ++++++++++++++++++++++++++++++++++++++++++++++++++++++++++++++++++++++++++++++++++++++++++++++++++++++++
#define swMix 0                      // V-Tail mixer switch (active LOW)
#define swTC 4                       // Throttle Cut pin (active LOW)
#define swDR 5                       // Dual Rate pin (active LOW)
//#define batPin A7                    // Battery pin (over 5V need voltage divider and value conversion to display)
#define buzzer PD6                   // Buzzer pin (buzzer with standalone sound generator)
#define buttonSelect 1               // Button for Menu/Select functions
#define buttonUp 2                   // Button for Up/Prev functions
#define buttonDown 3                 // Button for Down/Next functions
#define swA A6                       // Switch A Analog pin (active 0)
#define swB 12                       // Switch B Digital pin (active LOW)

// ++++++++++++++++++++++++++++++++++++++++++++++++++++++++++++++++++++++++++++++++++++++++++++++++++++++++
#define minBat 70                    // Minimum battery voltage for alarm (70 = 7.0V)
#define maxBat 82                    // Maximum battery voltage (10V) (82 = 8.2V)
// ++++++++++++++++++++++++++++++++++++++++++++++++++++++++++++++++++++++++++++++++++++++++++++++++++++++++

// ++++++++++++++++++++++++++++++++++++++++++++++++++++++++++++++++++++++++++++++++++++++++++++++++++++++++
// XBM image size for Model Selection screen
// ++++++++++++++++++++++++++++++++++++++++++++++++++++++++++++++++++++++++++++++++++++++++++++++++++++++++
#define airplane_width 55            // Pixel width of airplane image
#define airplane_height 46           // Pixel height of airplane image
// ++++++++++++++++++++++++++++++++++++++++++++++++++++++++++++++++++++++++++++++++++++++++++++++++++++++++

unsigned char chanTh = 2;                               // Throttle channel ID
unsigned char sw_status = 0x00;                         // 0:TC 1:DR
unsigned short int ppm[CHANNELS];                       // ppm output array
unsigned short int pots[CHANNELS];                      // Input ADC data array
unsigned short int calibration[CHANNELS][2];            // Min/Max value array for read channels and store calibration
unsigned short int raw_Pots[CHANNELS];                  // Read raw input pots array

// ++++++++++++++++++++++++++++++++++++++++++++++++++++++++++++++++++++++++++++++++++++++++++++++++++++++++
// Menu management variables
// ++++++++++++++++++++++++++++++++++++++++++++++++++++++++++++++++++++++++++++++++++++++++++++++++++++++++
unsigned char menuActual = 0;
unsigned char menuSubActual = 0;
unsigned char modelActual = 0;                // Added for Model Menu management
unsigned char menuSubModel = 0;               // Added for Model Menu management
unsigned char screen = 0;
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

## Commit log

2017-09-19 Add files via upload
    Eagle schematic of Arduino TX 6CH
2017-10-21 New schematic with Arduino Pro Mini
2017-10-23 Schematic update
    Schematic update to 5V power supply for original radio Turnigy/Flysky TX module
2017-11-01 Add files via upload
    Removed capacitor from pin AREF
2018-01-17 Arduino Nano general schematic update
    - Incorrect label of Arduino TX RX pins
    - Added debounce resistors on push buttons
    - Modified piezo buzzer driving (transistor powered from battery and buzzer connected on emitter)
2018-01-21 Added Eagle Cad Files
    Added Eagle Cad files for Arduino Nano PCB with TX module battery powered
    [ArduTX_TX_Battery_Powered.brd, ArduTX_TX_Battery_Powered.sch]
2018-01-28 Add files via upload
    Sketch file for optimize battery reading and test battery alarm through OLED display
2018-01-28 Update README.md
    ketch file for calibrate battery and testing low battery alarm with OLED display
